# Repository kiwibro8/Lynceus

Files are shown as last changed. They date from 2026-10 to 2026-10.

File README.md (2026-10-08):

# Lynceus - ESP32-S3 + HLK-LD2450 + ST7789

Sistem complet de monitorizare și urmărire radar în timp real, bazat pe microcontrollerul **ESP32-S3**, senzorul radar undă milimetrică de 24GHz **HLK-LD2450** și ecranul color **ST7789 320x240 SPI**.

<p align="center">
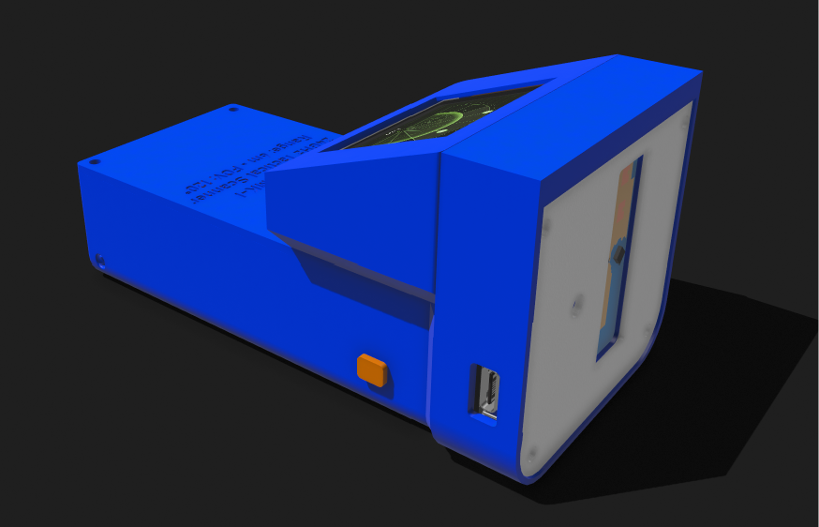
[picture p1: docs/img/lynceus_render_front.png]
Lynceus MK-I Front View
  
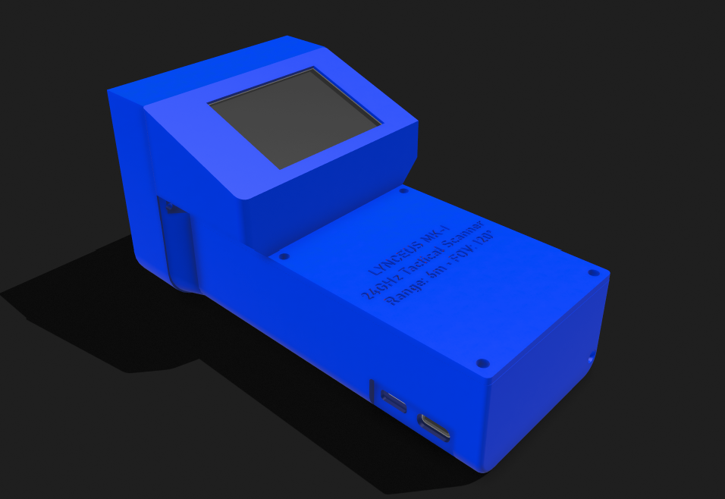
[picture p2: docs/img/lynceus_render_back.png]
Lynceus MK-I Isometric View
  
</p>

---

## 1. Caracteristici principale

- **Arhitectură Dual-Core pe ESP32-S3 (FreeRTOS):**
  - **Core 0:** Task dedicat de fundal pentru citirea continuă a radarului pe UART la 256.000 baud și procesarea filtrelor cinematice.
  - **Core 1:** Rulează bucla grafică (UI la ~35 FPS), controlul LED-ului RGB și procesarea comenzilor de la utilizator.
  - Datele sunt sincronizate în siguranță între nuclee prin stare partajată protejată cu spinlock (`portENTER_CRITICAL`).
- **Afișaj grafic rapid și fără pâlpâire (Double-Buffering):**
  - Comunicare SPI hardware la frecvența de **40 MHz**.
  - Randare completă în memorie (`GFXcanvas16`) înainte de afișare, eliminând complet efectul de pâlpâire (flicker-free).
  - Geometrie precalculată (Look-Up Table) pentru cercuri și linii radiale, evitând calcule trigonometrice costisitoare în fiecare cadru.
- **Filtrare avansată și urmărire cinematică 2D:**
  - **Filtru Anti-Ghost:** Confirmare multi-cadru și filtrare după unghiul conului util pentru eliminarea reflexiilor de pe pereți.
  - **Deadband Anti-Tremurat:** Când o persoană se oprește pe loc, poziția este blocată pe o ancoră fixă pentru a preveni fluctuațiile pe ecran.
  - **Vectori de viteză și urme (Trails):** Fiecare țintă are săgeată de direcție și o urmă vizuală estompată în timp.
- **Indicator vizual de proximitate (NeoPixel WS2812):**
  - Schimbă culoarea fluid în funcție de cel mai apropiat obiect:
    - Sub 1m: Roșu (pericol / apropiere mare)
    - 1m - 2m: Portocaliu
    - 2m - 3.5m: Galben / Verde
    - 3.5m - 5m: Cyan
    - Peste 5m: Albastru
    - Senzor deconectat: Roșu pulsant (efect respirație)

---

## 2. Conexiuni Hardware (Pinout)

### Conexiune Ecran ST7789 (320x240 SPI)
| Pin Ecran ST7789 | Pin ESP32-S3 | Funcție |
| :--- | :--- | :--- |
| **GND** | GND | Masă comună |
| **VCC** | 3.3V / 5V | Alimentare |
| **SCL** | GPIO 12 | SPI Clock (SCLK) |
| **SDA** | GPIO 11 | SPI Data (MOSI) |
| **RES** | GPIO 8 | Reset ecran |
| **DC**  | GPIO 9 | Data / Command |
| **CS**  | GPIO 10 | Chip Select |
| **BLK** | 3.3V (sau lăsat liber) | Backlight |

### Conexiune Radar HLK-LD2450
| Pin LD2450 | Pin ESP32-S3 | Funcție |
| :--- | :--- | :--- |
| **VCC** | 5V | Alimentare 5V |
| **GND** | GND | Masă comună |
| **TX**  | GPIO 4 | Radar TX -> ESP32 RX (256.000 baud) |
| **RX**  | GPIO 5 | Radar RX <- ESP32 TX (256.000 baud) |

---

## 3. Structura Proiectului

```
Lynceus/
├── cad/                  # Fisiere de fabricatie: STL (printare 3D) si STEP (ansamblu mecanic)
├── include/
│   ├── config.h          # Toate setările hardware, pini, culori și praguri
│   ├── radar_types.h     # Structurile de date pentru ținte și starea partajată
│   ├── ld2450.h          # Clasa radarului și definițiile funcțiilor
│   ├── display.h         # Managerul ecranului TFT ST7789
│   └── proximity_led.h   # Modulul de control pentru ledul RGB NeoPixel
├── src/
│   ├── ld2450.cpp        # Decodare pachete 30 bytes, task Core 0 și filtre
│   ├── display.cpp       # Desenare canvas, cercuri, săgeți și telemetrie
│   ├── proximity_led.cpp # Calculul gradientului de culoare după distanță
│   └── main.cpp          # Setup, loop cooperativ și comenzi Serial
├── platformio.ini        # Configurația PlatformIO (ESP32-S3, librării)
├── .gitignore            # Excludere foldere de build (.pio)
└── README.md             # Documentația proiectului
```

---

## 4. Comenzi Serial Monitor (Interactive)

Poți deschide consola Serial la viteza **115200 baud** și tasta următoarele comenzi în timp real:

| Tastă | Acțiune |
| :---: | :--- |
| **A** | Schimbă modul de acuratețe (`NORMAL` -> `PRECIZIE` -> `RAPID`) |
| **G** | Schimbă filtrul anti-reflexii (`ECHILIBRAT` -> `AGRESIV` -> `OPRIT / RAW`) |
| **M** | Activează modul Multi-Target (urmărește până la 3 persoane) |
| **S** | Activează modul Single-Target (concentrare pe 1 persoană) |
| **V** | Interoghează versiunea de firmware a radarului |
| **F** | Resetare la setările din fabrică ale senzorului |
| **R** | Repornire software (reboot) a senzorului |
| **O** | Rotește afișajul ecranului cu 180° |
| **Z** | Comută scara de vizualizare (Zoom 3m <-> Normal 6m) |
| **?** | Afișează lista de ajutor cu toate comenzile |

---

## 5. Compilare și Încărcare (PlatformIO)

Din terminal sau din bara de jos din VS Code / PlatformIO:

```bash
# Compilare proiect
pio run

# Încărcare pe placa ESP32-S3
pio run -t upload
```

---

## 6. Modelare 3D & Credite CAD (Acknowledgments)

Carcasa tactică a radarului **Lynceus MK-I** a fost proiectată special pentru integrarea componentelor și imprimare 3D (fișierele de fabricație se află în directorul `cad/`).

Pentru realizarea ansamblului CAD mecanic (toleranțe, decupaj USB, fixări pe distanțiere și unghi de vizualizare radar), au fost utilizate ca modele dimensionale de referință următoarele piese electronice COTS din comunitatea GrabCAD:
- **Modul ESP32-S3:** [ESP32-S3-WROOM-1](https://grabcad.com/library/esp32-s3-wroom-1-1) (GrabCAD)
- **Senzor radar mmWave:** [HLK-LD2450 24G Human Presence Sensor](https://grabcad.com/library/hlk-ld2450-24g-human-presence-sensor-millimeter-wave-radar-module-1) (GrabCAD)
- **Shield alimentare 18650:** [18650 Battery Shield V8](https://grabcad.com/library/18650-battery-shield-v8_enclosure_r2-1) (GrabCAD)

---

*Lynceus MK-I — Sistem radar tactic mmWave pentru cercetare și prototipare embedded.*

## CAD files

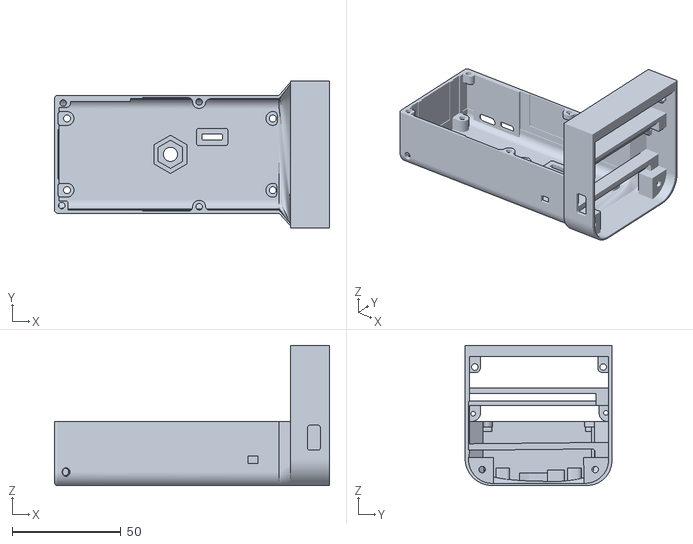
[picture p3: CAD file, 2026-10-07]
CAD/STL/mainBody.stl
126.6 x 67.6 x 64.7

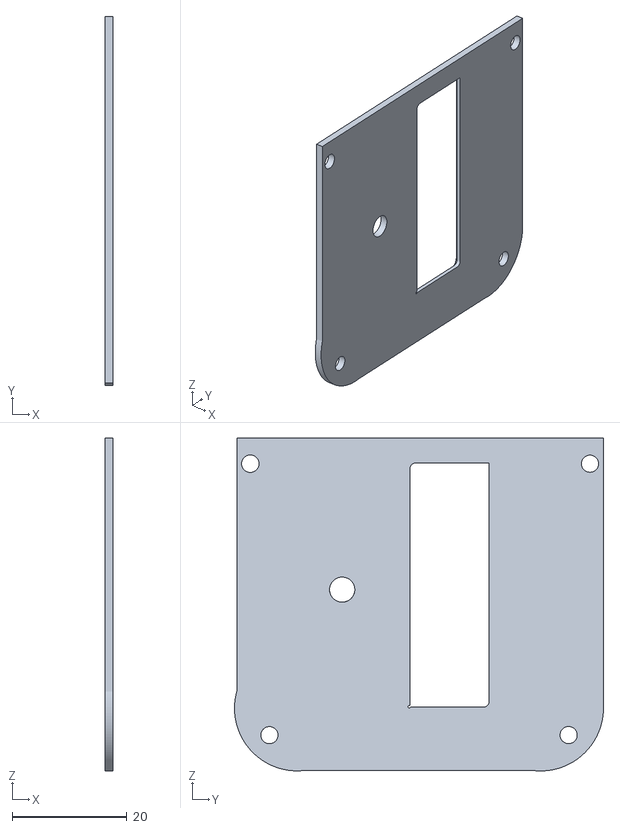
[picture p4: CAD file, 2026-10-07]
CAD/STL/FrontOuter.stl
1.45 x 64.2 x 57.9

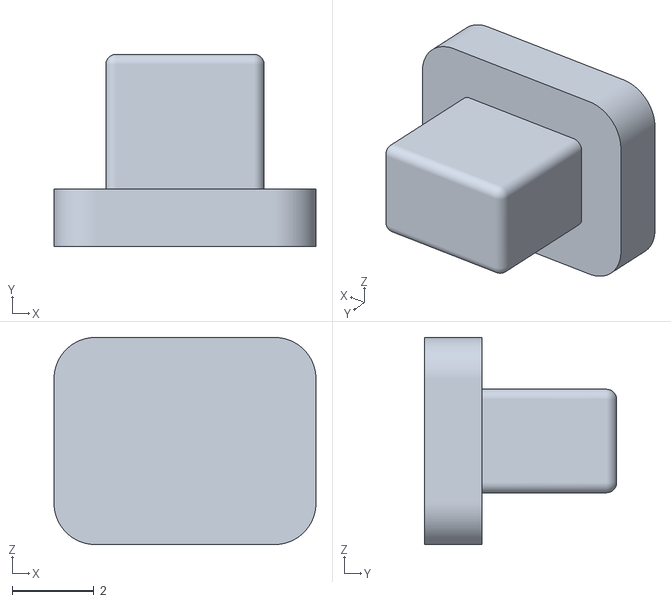
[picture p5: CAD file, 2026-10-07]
CAD/STL/button.stl
6.43 x 4.72 x 5.08

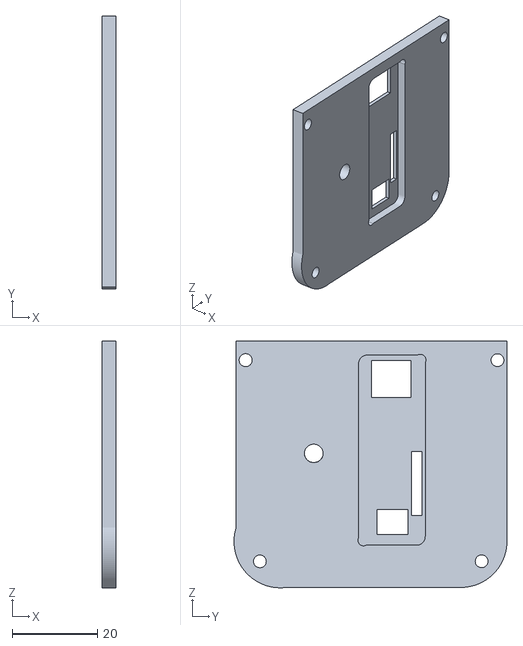
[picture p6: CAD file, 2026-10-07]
CAD/STL/Front.stl
3.29 x 64.1 x 57.9

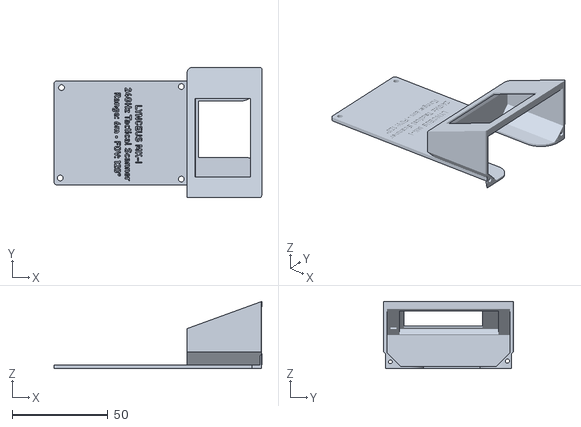
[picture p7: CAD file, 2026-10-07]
CAD/STL/Screen.stl
108.7 x 68.1 x 35.2

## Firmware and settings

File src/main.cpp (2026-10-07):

#include <Arduino.h>
#include "config.h"
#include "radar_types.h"
#include "ld2450.h"
#include "display.h"
#include "proximity_led.h"

// lynceus mk-i firmware (esp32-s3)
// Core 0 citeste radarul pe serial la 256k si filtreaza tintele
// Core 1 deseneaza ecranul la ~35 fps si asculta comenzile din serial

// instantiem obiectele principale ale aplicatiei
LD2450Radar    radar;   // driverul radarului mmWave HLK-LD2450 (creeaza task-ul pe Core 0)
DisplayManager display; // motorul grafic pentru ecranul ST7789 (gestioneaza canvas-ul din RAM)
ProximityLED   proxLed; // indicatorul optic RGB NeoPixel de pe placa (GPIO 48)

// variabile pentru temporizare neblocanta (inlocuiesc functia clasica delay() ca sa nu blocam procesorul)
unsigned long lastUiUpdate = 0;
unsigned long lastSerialTelemetry = 0;

// afiseaza un raport text complet in consola seriala o data pe secunda (telemetrie 1 Hz)
void printSerialTelemetry(const CODSharedState &state, bool connected) {
  Serial.println("-------------------------------------------------");
  const char* fltStr = (state.filterMode == GHOST_FILTER_AGGRESSIVE) ? "AGRESIV" :
                       (state.filterMode == GHOST_FILTER_OFF) ? "FARA FILTRU (RAW)" : "ECHILIBRAT";
  const char* accStr = (state.accuracyMode == ACCURACY_PRECISION)  ? "PRECIZIE" :
                       (state.accuracyMode == ACCURACY_RESPONSIVE) ? "RAPID" : "NORMAL";

  Serial.printf("Radar: %s | Mod: %s | Filtru: %s | Acuratete: %s | Scala: %s\n",
                connected ? "CONECTAT" : "DECONECTAT",
                state.multiTargetActive ? "MULTI-TINTA" : "O SINGURA TINTA",
                fltStr, accStr,
                display.isCqbMode() ? "3 Metri (Zoom)" : "6 Metri (Normal)");

  Serial.printf("Tinte detectate: %d | Cel mai apropiat obiect: %d mm\n",
                state.activeCount, proxLed.getLastMinDist());

  unsigned long now = millis();
  for (int i = 0; i < MAX_TARGETS; i++) {
    if (state.targets[i].valid) {
      const auto &t = state.targets[i];
      // afisam coordonatele spatiale in milimetri si viteza in cm/s
      Serial.printf("  [Tinta %d] Distanta: %5d mm | X: %+5d mm | Y: %5d mm | Viteza: %3d cm/s (Vx=%+3d, Vy=%+3d) %s\n",
                    t.id, t.distance, t.x, t.y, t.speed, t.vx, t.vy,
                    t.isHeld ? "[RETINUT PE LOC]" : "[IN MISCARE]");
    } else {
      Serial.printf("  [Tinta %d] -\n", i + 1);
    }
  }
}

// citeste comenzile primite de la utilizator prin consola seriala (tastate in Serial Monitor)
void handleSerialCommands() {
  while (Serial.available() > 0) {
    char cmd = (char)toupper((unsigned char)Serial.read());

    switch (cmd) {
      // tasta 'A': comuta modul de acuratete (Tactical -> Precision -> Responsive)
      case 'A': {
        AccuracyMode curent = radar.getAccuracyMode();
        AccuracyMode urmator = (curent == ACCURACY_TACTICAL)   ? ACCURACY_PRECISION :
                               (curent == ACCURACY_PRECISION)  ? ACCURACY_RESPONSIVE :
                                                                 ACCURACY_TACTICAL;
        radar.setAccuracyMode(urmator);

        if (urmator == ACCURACY_PRECISION) {
          Serial.println("Mod acuratete: PRECIZIE (ancora la 4.5cm, blocheaza tremuratul pe loc)");
        } else if (urmator == ACCURACY_RESPONSIVE) {
          Serial.println("Mod acuratete: RAPID (deadband 1.5cm, reactioneaza instant la miscare)");
        } else {
          Serial.println("Mod acuratete: NORMAL (echilibrat, deadband 3.0cm)");
        }
        break;
      }

      // tasta 'G': comuta filtrul anti-ghost (Balanced -> Aggressive -> Off)
      case 'G': {
        GhostFilterMode curent = radar.getGhostFilterMode();
        GhostFilterMode urmator = (curent == GHOST_FILTER_BALANCED)   ? GHOST_FILTER_AGGRESSIVE :
                                  (curent == GHOST_FILTER_AGGRESSIVE) ? GHOST_FILTER_OFF        :
                                                                        GHOST_FILTER_BALANCED;
        radar.setGhostFilterMode(urmator);

        if (urmator == GHOST_FILTER_AGGRESSIVE) {
          Serial.println("Filtru: AGRESIV (con 90 grade, taie peretii laterali si cere 5 confirmari)");
        } else if (urmator == GHOST_FILTER_OFF) {
          Serial.println("Filtru: OPRIT (afiseaza date brute direct din radar)");
        } else {
          Serial.println("Filtru: ECHILIBRAT (con normal 110 grade, 3 confirmari)");
        }
        break;
      }

      // tasta 'M': activeaza modul Multi-Target (senzorul poate urmari pana la 3 persoane simultan)
      case 'M': {
        Serial.print("Trimitere comanda Multi-Target catre senzor... ");
        bool ok = radar.setMultiTargetMode(true);
        Serial.println(ok ? "Gata!" : "Eroare la configurare!");
        break;
      }

      // tasta 'S': activeaza modul Single-Target (senzorul urmareste doar cea mai puternica tinta)
      case 'S': {
        Serial.print("Trimitere comanda Single-Target catre senzor... ");
        bool ok = radar.setMultiTargetMode(false);
        Serial.println(ok ? "Gata!" : "Eroare la configurare!");
        break;
      }

      // tasta 'V': cere versiunea interna de firmware a modulului radar LD2450
      case 'V': {
        Serial.print("Interogare versiune firmware radar... ");
        String ver = radar.queryFirmwareVersion();
        if (ver.length() > 0) {
          Serial.print("Versiune firmware radar: ");
          Serial.println(ver);
        } else {
          Serial.println("Senzorul nu a raspuns.");
        }
        break;
      }

      // tasta 'F': resetare software completa a senzorului la setarile din fabrica
      case 'F': {
        Serial.println("Resetare radar la setarile din fabrica...");
        bool ok = radar.factoryReset();
        Serial.println(ok ? "Resetat cu succes!" : "Gata.");
        break;
      }

      // tasta 'R': comanda senzorului sa faca un reboot software
      case 'R': {
        Serial.print("Repornire senzor (reboot)... ");
        radar.reboot();
        Serial.println("Gata!");
        break;
      }

      // tasta 'O': roteste orientarea ecranului cu 180 de grade
      case 'O': {
        uint8_t rotCurenta = display.getOrientation();
        uint8_t rotNoua = (rotCurenta == 3) ? 1 : 3;
        display.setOrientation(rotNoua);
        Serial.printf("Rotatie ecran schimbata la: %d\n", rotNoua);
        break;
      }

      // tasta 'Z': schimba scala radarului intre 3 metri (CQB Zoom) si 6 metri (Normal)
      case 'Z': {
        display.toggleRangeMode();
        Serial.printf("Scala radar: %s\n",
                      display.isCqbMode() ? "3 Metri (Zoom Apropiat)" : "6 Metri (Normal)");
        break;
      }

      // tasta '?' sau 'H': afiseaza meniul cu toate comenzile disponibile
      case '?':
      case 'H': {
        Serial.println("\n--- Comenzi Disponibile in Consola ---");
        Serial.println("  [a] Schimba modul de acuratete (Normal -> Precizie -> Rapid)");
        Serial.println("  [g] Schimba filtrul anti-ghost (Echilibrat -> Agresiv -> Oprit)");
        Serial.println("  [m] Activeaza modul multi-tinta (3 persoane)");
        Serial.println("  [s] Activeaza modul o singura tinta");
        Serial.println("  [v] Afiseaza versiunea de firmware");
        Serial.println("  [f] Resetare la setarile din fabrica");
        Serial.println("  [r] Reporneste senzorul (reboot)");
        Serial.println("  [o] Roteste ecranul cu 180 de grade");
        Serial.println("  [z] Schimba distanta (3m Zoom / 6m Normal)\n");
        break;
      }

      default:
        break;
    }
  }
}

// functia de initializare la alimentarea placii ESP32-S3
void setup() {
  // pornim portul serial USB la viteza standard de 115200 baud
  Serial.begin(115200);
  delay(1000); // pauza scurta de o secunda ca sa aiba timp portul COM din PC sa se deschida

  Serial.println("\n--- RADAR HLK-LD2450 ESP32-S3 (LYNCEUS MK-I) ---");

  // Pasul 1: initializam ecranul TFT ST7789 si alocam memoria RAM pentru Double-Buffering
  Serial.print("Pornire ecran ST7789 (SPI 40MHz)... ");
  if (display.begin()) {
    Serial.println("OK");
  } else {
    Serial.println("EROARE CRITICA LA ECRAN");
  }

  // Pasul 2: initializam portul serial al radarului si lansam task-ul FreeRTOS pe Core 0
  Serial.print("Pornire radar LD2450 (UART 256.000 baud pe Core 0)... ");
  if (radar.begin(Serial1, RADAR_RX_PIN, RADAR_TX_PIN, RADAR_BAUD)) {
    Serial.println("OK");
  } else {
    Serial.println("EROARE LA RADAR");
  }

  // Pasul 3: pornim ledul RGB NeoPixel de pe placa (GPIO 48) si facem un test scurt de culori
  proxLed.begin();

  Serial.println("Sistemul a pornit cu succes! Tasteaza '?' in consola pentru comenzi.\n");
}

// bucla principala care ruleaza continuu pe Nucleul 1 (Core 1)
void loop() {
  // Pasul 1: verificam daca utilizatorul a tastat comenzi in consola seriala
  handleSerialCommands();

  // Pasul 2: preluam un instantaneu complet al datelor radarului de pe Nucleul 0.
  // apelul getSnapshot() foloseste spinlock hardware (portENTER_CRITICAL),
  // garantand ca nu citim coordonate pe jumatate scrise de Core 0.
  CODSharedState state = radar.getSnapshot();
  unsigned long now = millis();

  // verificam daca radarul inca emite date (daca nu a mai trimis nimic de 1.5s, e offline)
  bool connected = (state.lastHeartbeatMs > 0 && (now - state.lastHeartbeatMs < SENSOR_DEAD_MS));

  // Pasul 3: actualizam culoarea LED-ului RGB in functie de cel mai apropiat obiect
  proxLed.update(state, connected);

  // Pasul 4: randam ecranul la intervale regulate de 28 milisecunde (~35 FPS)
  unsigned long elapsed = now - lastUiUpdate;
  if (elapsed >= UI_REFRESH_INTERVAL_MS) {
    lastUiUpdate = now;
    display.render(state, connected);
  } else {
    // daca am terminat randarea mai repede de 28ms, lasam procesorul sa se odihneasca scurt,
    // evitand ca bucla while/loop sa consume 100% CPU inutil
    unsigned long ramase = UI_REFRESH_INTERVAL_MS - elapsed;
    if (ramase > 2) delay(ramase - 1);
    else delay(1);
  }

  // Pasul 5: emitem raportul de telemetrie in consola seriala o data pe secunda (1 Hz)
  if (now - lastSerialTelemetry >= SERIAL_TELEMETRY_MS) {
    lastSerialTelemetry = now;
    printSerialTelemetry(state, connected);
  }
}

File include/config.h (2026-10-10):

#pragma once
#include <Arduino.h>

// configurari hardware si parametri pentru radar

// pini ecran st7789 (spi pe esp32-s3)
#define TFT_MOSI 11 // date spi (sda / mosi)
#define TFT_SCLK 12 // ceas spi (scl / sck la 40mhz)
#define TFT_CS   10 // chip select
#define TFT_DC   9  // data / command
#define TFT_RST  8  // reset hardware ecran
#define TFT_BLK  -1 // backlight legat direct la 3.3v

// rezolutie si orientare ecran
#define SCREEN_WIDTH    320
#define SCREEN_HEIGHT   240
#define SCREEN_ROTATION 1   // mod landscape

// moduri de distanta (in milimetri)
#define RADAR_RANGE_CQB     3000.0f // mod cqb: zoom la 3 metri
#define RADAR_RANGE_LONG    6000.0f // mod normal: 6 metri
#define RADAR_DEFAULT_RANGE RADAR_RANGE_LONG

// dimensiuni canvas in ram (double buffering ca sa nu palpaie ecranul)
#define CANVAS_WIDTH    320
#define CANVAS_HEIGHT   240
#define CANVAS_Y_OFFSET 0
// pozitia noastra pe ecran: centrat pe x, jos pe y
#define CANVAS_ORIGIN_X 160 
#define CANVAS_ORIGIN_Y 235 

#define MAX_TARGETS 3 // radarul stie sa urmareasca maxim 3 tinte o data

// persistenta tintelor pe ecran (milisecunde) - adaptata pentru ciclul respirator (3-4 secunde)
#define TARGET_STALE_BRIGHT_MS 500  // punct aprins in primele 500ms
#define TARGET_STALE_ORANGE_MS 1600 // devine mai pal daca radarul pierde semnalul pe zero-crossing
#define TARGET_STALE_REMOVE_MS 3800 // coasting extins: retinem pozitia 3.8 secunde peste pauzele respiratorii
#define TARGET_HOLD_BRIEF_MS   800  // retinere pentru tinte statice noi
#define SENSOR_DEAD_MS         1500 // intram in modul offline daca nu mai primim date 1.5s
#define RADAR_MIN_DIST_MM      350  // ignoram sub 35cm (carcasa sau degetele noastre)

// unghi de vizualizare (fov)
// folosim tangenta unghiului (|x| <= y * tan) pentru ca e mult mai rapida decat atan2
#define RADAR_MAX_FOV_TAN_BAL  1.428f  // 110 grade (mod normal echilibrat - optim pentru scanare)
#define RADAR_MAX_FOV_TAN_AGGR 1.000f  // 90 grade (mod agresiv pentru holuri/spatii inguste)
#define RADAR_MAX_FOV_TAN_RAW  1.732f  // 120 grade (tot conul senzorului, fara filtrare)
#define RADAR_MAX_FOV_TAN      RADAR_MAX_FOV_TAN_BAL

// praguri ca sa scapam de reflexii false si fantome
#define HUMAN_MIN_MOVE_SPEED_CMS 8    // un om care merge are minim 8 cm/s
#define STATIC_GHOST_HITS_MIN    20   // daca nu se misca, cerem 20 cadre la rand ca sa fim siguri
#define GHOST_CONFIRM_HITS_BALANCED   3    // omul in miscare trebuie vazut in 3 cadre consecutive
#define GHOST_CONFIRM_HITS_AGGRESSIVE 5    // 5 cadre in modul agresiv
#define GHOST_MAX_JUMP_MM             1200 // salt maxim admis intr-un cadru (1.2m la 50ms)
#define GHOST_MIN_TARGET_SEP_MM       350  // distanta minima intre doua persoane diferite

// stabilizare cand omul sta pe loc (zona moarta ca sa nu tremure pe ecran)
#define TRACK_DEADBAND_MM_PRECISION    45.0f // zona moarta 4.5 cm in mod precizie
#define TRACK_DEADBAND_MM_TACTICAL     30.0f // zona moarta 3.0 cm in mod normal
#define TRACK_DEADBAND_MM_RESPONSIVE   15.0f // zona moarta 1.5 cm in mod rapid
#define STATIONARY_SPEED_THRESHOLD_CMS 8     // sub 8 cm/s consideram ca sta pe loc
#define STATIONARY_LOCK_TIME_MS        350   // dupa 350ms blocam pozitia pe ancora
#define TRACK_ASSOCIATION_GATE_MM      900   // daca e la sub 90cm de pozitia veche, e aceeasi persoana

// anti centroid hopping (cand omul sta la birou si misca doar mouse-ul)
// bratul are intre 28 si 95 cm fata de corp, asa ca radarul sare intre piept si mana
#define LIMB_HOP_MIN_DIFF_MM           280.0f // distanta minima piept - mana
#define LIMB_HOP_MAX_DIFF_MM           950.0f // distanta maxima brat intins
#define LIMB_HOP_MAX_ANGLE_RAD         0.45f  // unghiul conului in care se misca mana (~25 grade)
#define LIMB_HOP_SUSTAIN_FRAMES        18     // cerem 18 cadre sustinute ca sa mutam ancora daca chiar s-a ridicat
#define AZIMUTH_DEADBAND_RAD           0.035f // zona moarta de 2 grade pe azimut (elimina reflexiile de pe laptop/birou)
#define AZIMUTH_SMOOTH_FACTOR          0.08f  // filtrare lina pe unghi
#define QUASI_STATIC_HOLD_MS           500    // dupa 500ms de stat nemiscat activam protectia

// coada de puncte pentru efectul de miscare (trail)
#define TRAIL_LEN       10 // tinem minte ultimele 10 pozitii
#define TRAIL_SAMPLE_MS 60 // salvam un punct la fiecare 60ms

// sageata de directie a vitezei
#define ARROW_MIN_SPEED_CMS 5   // nu desenam sageata daca merge cu sub 5 cm/s
#define ARROW_MAX_SPEED_CMS 150 // viteza maxima scalata (1.5 m/s)
#define ARROW_LEN_MIN       6   // lungime minima sageata
#define ARROW_LEN_MAX       22  // lungime maxima sageata

// conexiune serial uart cu radarul ld2450
#define RADAR_RX_PIN 4      // pin rx esp32 (legat la tx radar)
#define RADAR_TX_PIN 5      // pin tx esp32 (legat la rx radar)
#define RADAR_BAUD   256000 // baudrate radar
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

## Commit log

2026-10-07 Add CAD credits and 3D enclosure references
2026-10-07 CAD Files
    The STL folder is for quick printing. Keep in mind that the front outer is not required if you have good tolerances on your printer
    [Front.stl, FrontOuter.stl, Screen.stl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]
2026-10-07 Simplify battery shield credit
2026-10-08 Add 3D case renders to documentation
2026-10-10 Set optimal defaults for field testing (Single-Target, Aggressive filter, Precision)
2026-10-19 Add BOM and 3D printing details to README
2026-10-20 new case renders
